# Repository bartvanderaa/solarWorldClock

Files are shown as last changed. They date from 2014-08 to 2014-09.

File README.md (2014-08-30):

solarWorldClock
===============

The Arduino based Solar World Clock<br>

Bart van der Aa<br>
info@bartvanderaa.com<br>
2013-2014<br>
 
General notes:<br>
The Solar World Clock (SWC) project has been in my mind for about 10 years now, and finally I found a suitable platform (the Arduino) to actually built it. 
But, first things first, what is the WSC project about? And secondly, how can we built one?<br>

The first question is actually fairly easy to answer. Imagine the map of the world where the sun's intensity is projected on the surface of this map. One could read the approximate time by tracing the location of the sun, just by identifying on which parts of the globe it is day- or nighttime. This, in brief, is the working principle of the WSC. Obviously, it is difficult to know the time in absolute terms, but who needs that anyway ;-) <br>
 
Notes on algorithm:<br>
The program uses a real-time-clock (RTC) to keep track of date and time. Based on date, time, and location the solar intensity is computed. A vector of intensity values (0-255) is then send to ShiftPWM to control an array of LEDs. Time can now be read based on the digitally projected solar intensity. <br>
 
Sunset-Sunrise part:<br>
Eastern longitude positive, Western longitude negative, Northern latitude positive and Southern latitude negative. <br>
 
PWM part:<br>
If flickering of the LEDs occurs try to adjust the PWM frequency.<br>
 
Credits go to:<br>
Solar intensity part by The Renewable Resource Data Center (RReDC), downloaded 2014;<br>
RTC part by Michael Margolis, downloaded 2014<br>
PWM part by Elco Jacobs, updated August 2012<br>

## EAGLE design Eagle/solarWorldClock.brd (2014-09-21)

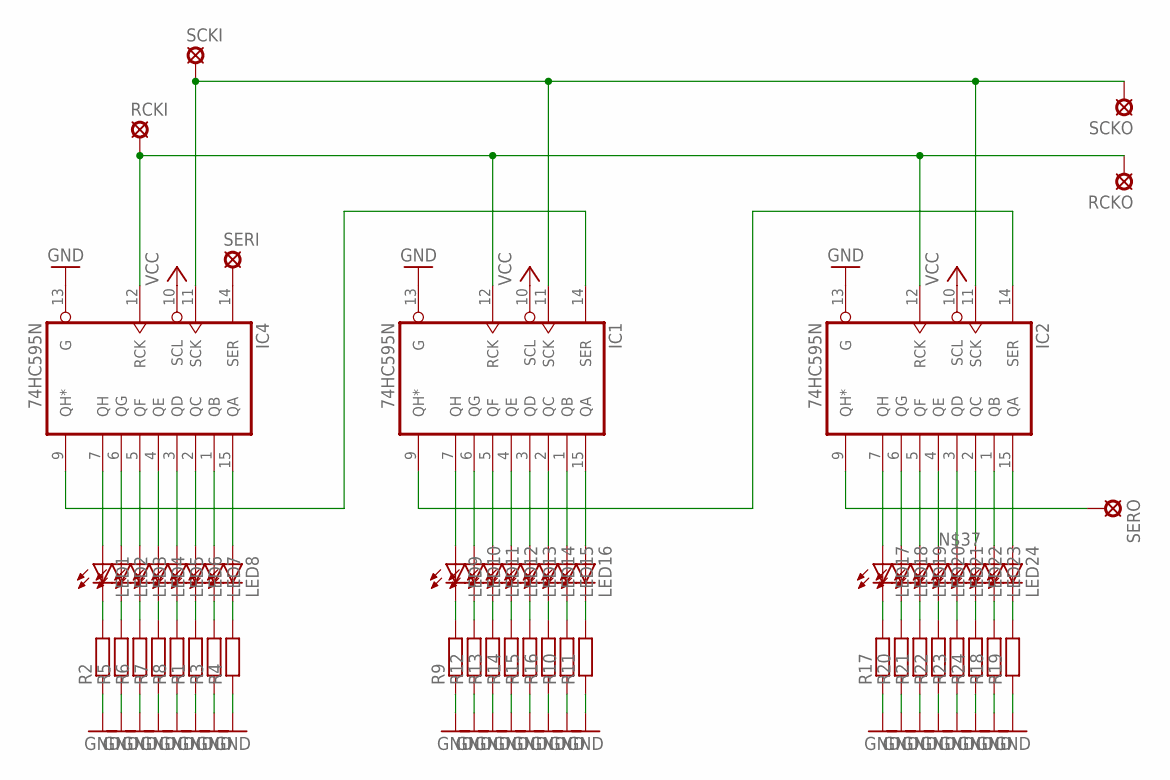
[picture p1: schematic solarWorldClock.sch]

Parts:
IC1, IC2, IC4: 74HC595N; DIL16
LED1, LED2, LED3, LED4, LED5, LED6, LED7, LED8, LED9, LED10, LED11, LED12, LED13, LED14, LED15, LED16, LED17, LED18, LED19, LED20, LED21, LED22, LED23, LED24: LEDLZR181; LZR181
R1, R2, R3, R4, R5, R6, R7, R8, R9, R10, R11, R12, R13, R14, R15, R16, R17, R18, R19, R20, R21, R22, R23, R24: R-EU_0207/7; 0207/7
RCKI: LSP10
RCKO: LSP10
SCKI: LSP10
SCKO: LSP10
SERI: LSP10
SERO: LSP10

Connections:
GND: IC1.8 (GND), IC1.13 (G), IC2.8 (GND), IC2.13 (G), IC4.8 (GND), IC4.13 (G), R1.1, R2.1, R3.1, R4.1, R5.1, R6.1, R7.1, R8.1, R9.1, R10.1, R11.1, R12.1, R13.1, R14.1, R15.1, R16.1, R17.1, R18.1, R19.1, R20.1, R21.1, R22.1, R23.1, R24.1
unnamed: IC4.7 (QH), LED1.A
unnamed: LED1.K (C), R2.2
unnamed: IC4.6 (QG), LED2.A
unnamed: IC4.5 (QF), LED3.A
unnamed: IC4.4 (QE), LED4.A
unnamed: IC4.3 (QD), LED5.A
unnamed: IC4.2 (QC), LED6.A
unnamed: IC4.1 (QB), LED7.A
unnamed: IC4.15 (QA), LED8.A
unnamed: LED2.K (C), R5.2
unnamed: LED3.K (C), R6.2
unnamed: LED4.K (C), R7.2
unnamed: LED5.K (C), R8.2
unnamed: LED6.K (C), R1.2
unnamed: LED7.K (C), R3.2
unnamed: LED8.K (C), R4.2
unnamed: IC1.7 (QH), LED9.A
unnamed: IC1.6 (QG), LED10.A
unnamed: IC1.5 (QF), LED11.A
unnamed: IC1.4 (QE), LED12.A
unnamed: IC1.3 (QD), LED13.A
unnamed: IC1.2 (QC), LED14.A
unnamed: IC1.1 (QB), LED15.A
unnamed: IC1.15 (QA), LED16.A
unnamed: LED9.K (C), R9.2
unnamed: LED10.K (C), R12.2
unnamed: LED11.K (C), R13.2
unnamed: LED12.K (C), R14.2
unnamed: LED13.K (C), R15.2
unnamed: LED14.K (C), R16.2
unnamed: LED15.K (C), R10.2
unnamed: LED16.K (C), R11.2
unnamed: IC2.9 (QH*), SERO.MP
unnamed: IC1.14 (SER), IC4.9 (QH*)
unnamed: IC2.7 (QH), LED17.A
unnamed: IC2.6 (QG), LED18.A
unnamed: IC2.5 (QF), LED19.A
unnamed: IC2.4 (QE), LED20.A
unnamed: IC2.3 (QD), LED21.A
unnamed: IC2.2 (QC), LED22.A
unnamed: IC2.1 (QB), LED23.A
unnamed: IC2.15 (QA), LED24.A
unnamed: LED17.K (C), R17.2
unnamed: LED18.K (C), R20.2
unnamed: LED19.K (C), R21.2
unnamed: LED20.K (C), R22.2
unnamed: LED21.K (C), R23.2
unnamed: LED22.K (C), R24.2
unnamed: LED23.K (C), R18.2
unnamed: LED24.K (C), R19.2
unnamed: IC1.9 (QH*), IC2.14 (SER)
unnamed: IC1.12 (RCK), IC2.12 (RCK), IC4.12 (RCK), RCKI.MP, RCKO.MP
unnamed: IC1.11 (SCK), IC2.11 (SCK), IC4.11 (SCK), SCKI.MP, SCKO.MP
unnamed: IC4.14 (SER), SERI.MP
VCC: IC1.10 (SCL), IC1.16 (VCC), IC2.10 (SCL), IC2.16 (VCC), IC4.10 (SCL), IC4.16 (VCC)

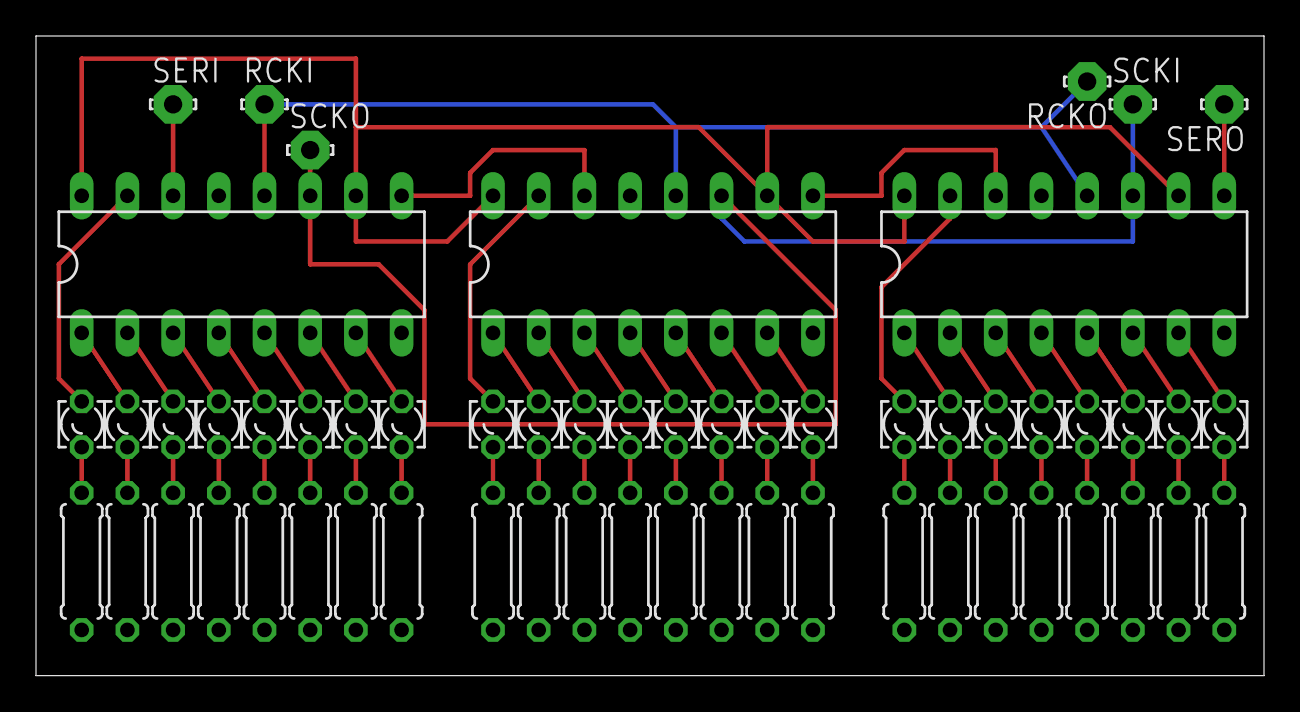
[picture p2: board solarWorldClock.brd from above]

Board: 2 copper layers, 68.2 x 35.5 mm, 57 parts (0 on the bottom side), 56 nets.

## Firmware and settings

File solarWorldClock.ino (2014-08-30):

/**********************************************************************
 SolarWorldClock
 Bart van der Aa
 info@bartvanderaa.com
 2013-2014
 
 General notes:
 The Solar World Clock (SWC) project has been in my mind for about 10 years now, and finally I found a suitable platform (the Arduino) to actually built it. 
 But, first things first, what is the WSC project about? And secondly, how can we built one?

 The first question is actually fairly easy to answer. Imagine the map of the world where the sun's intensity is projected on the surface of this map.   
 One could read the approximate time by tracing the location of the sun, just by identifying on which parts of the globe it is day- or nighttime. 
 This, in brief, is the working principle of the WSC. Obviously, it is difficult to know the time in absolute terms, but who needs that anyway ;-)
 
 Notes on alorithm:
 The program uses a real-time-clock (RTC) to keep track of date and time. Based on date, time, and location the solar intensity is computed.
 A vector of intensity values (0-255) is then send to ShiftPWM to control an array of LEDs. Time can now be read based on the digitally projected solar intensity. 
 
 Sunset-Sunrise part:
 Eastern longitude positive, Western longitude negative       
 Northern latitude positive, Southern latitude negative
 
 PWM part:
 If flickering of the LEDs occurs try to adjust the PWM frequency.
 
 Credits go to:
 Solar intensity part by The Renewable Resource Data Center (RReDC), downloaded 2014
 RTC part by Michael Margolis, downloaded 2014 
 PWM part by Elco Jacobs, updated August 2012
 
 ***********************************************************************/

// Initialize Shift PWM before loading libraries. Note that dataPin and clockPin are predefined on pin 11 and pin 13, respectively.
const int ShiftPWM_latchPin = 4;
const bool ShiftPWM_invertOutputs = false;
const bool ShiftPWM_balanceLoad = false;

// Include other libraries
#include <ShiftPWM.h>
#include <Wire.h>
#include "RTClib.h"  
#include <stdio.h>
#include <math.h>
#include <stdlib.h>
#include <string.h>
#include "solpos00.h" 

// Initialize RTC
RTC_DS1307 RTC;

// Initialize shift-registers
void inOutAll(void);
unsigned char maxBrightness = 255;
unsigned char pwmFrequency = 75;
unsigned int numRegisters = 3;
unsigned int numOutputs = numRegisters*8;

// Coordinate settings
double lat = 00.70;// 57.70; // lattitude, Göteborg
double lonVec[] = {
  -165, -150, -135, -120, -105, -90, -75, -60, -45, -30, -15, 0, 15, 30, 45, 60, 75, 90, 105, 120, 135, 150, 165, 180}; // Time-zone central longitude coordiantes 
double intensityVec[24];
//int normIntensity[24];
double maxIntensity = 1375; 

int *normIntensity = (int*)calloc(24,sizeof(int));

/*============================================================================*/
// Setup loop
/*============================================================================*/
void setup(){

  // Begin the Serial connection 
  Serial.begin(9600);

  // Instantiate the RTC
  Wire.begin();
  RTC.begin();

  // Check if the RTC is running.
  if (! RTC.isrunning()) {
    Serial.println("RTC is NOT running");
  }

  // This section grabs the current datetime and compares it to
  // the compilation time.  If necessary, the RTC is updated.
  DateTime now = RTC.now();
  DateTime compiled = DateTime(__DATE__, __TIME__);
  if (now.unixtime() < compiled.unixtime()) {
    Serial.println("RTC is older than compile time! Updating");
    RTC.adjust(DateTime(__DATE__, __TIME__));
  }
  
  // Sets the number of 8-bit registers that are used.
  ShiftPWM.SetAmountOfRegisters(numRegisters);
  
  // Set PWM frequency and Maximum brightness
  ShiftPWM.Start(pwmFrequency,maxBrightness);
  
  Serial.println("Setup complete.");
}

/*============================================================================*/
// main loop 
/*============================================================================*/
void loop(){    

  // Solar intensity alg initi
  struct posdata pd, *pdat;
  long retval;
  pdat = &pd;
  S_init(pdat);

  // Get actual time and reformat
  DateTime now = RTC.now();   
  pdat->function &= ~S_DOY;
  pdat->month = now.month();
  pdat->day   = now.day();
  pdat->year  = now.year(); 
  pdat->hour  = now.hour();
  pdat->minute = now.minute();
  pdat->second = now.second();
  pdat->timezone  = 1.0;

  // Solar intensity
  pdat->latitude  =  lat; 
  for (int ii=0; ii<24; ii++){  
    pdat->longitude = lonVec[ii];
    retval = S_solpos(pdat);
    intensityVec [ii] = pdat->etr;
    normIntensity[ii] = round((pdat->etr)/maxIntensity*255);
  }  

  if(Serial.available()){
    if(Serial.peek() == 'l'){
      // Print information about the interrupt frequency, duration and load on your program
      ShiftPWM.PrintInterruptLoad();
    }
    while (Serial.read() >= 0){
      ; // flush remaining characters
    }
  }
  
  // Switch all Pins on
  ShiftPWM.Set24Pins(normIntensity);

  
  // Display the current time
  Serial.print("Current time: ");
  Serial.print(now.year(), DEC);
  Serial.print('/');
  Serial.print(now.month(), DEC);
  Serial.print('/');
  Serial.print(now.day(), DEC);
  Serial.print(' ');
  Serial.print(now.hour(), DEC);
  Serial.print(':');
  Serial.print(now.minute(), DEC);
  Serial.print(':');
  Serial.print(now.second(), DEC);
  
  Serial.println();
  for (int ii=0; ii<24; ii++){
    Serial.print(normIntensity[ii]);
    Serial.println();
  } 
  
  Serial.println();
  delay(5000);
}

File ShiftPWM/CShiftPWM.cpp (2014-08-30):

/*
CShiftPWM.cpp - ShiftPWM.h - Library for Arduino to PWM many outputs using shift registers
Copyright (c) 2011-2012 Elco Jacobs, www.elcojacobs.com
All right reserved.

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
You should have received a copy of the GNU Lesser General Public
License along with this library; if not, write to the Free Software
Foundation, Inc., 51 Franklin St, Fifth Floor, Boston, MA  02110-1301  USA
*/

/* workaround for a bug in WString.h */
#define F(string_literal) (reinterpret_cast<const __FlashStringHelper *>(PSTR(string_literal)))

#include "CShiftPWM.h"
#include <Arduino.h>

CShiftPWM::CShiftPWM(int timerInUse, bool noSPI, int latchPin, int dataPin, int clockPin) :  // Constants are set in initializer list
					m_timer(timerInUse), m_noSPI(noSPI), m_latchPin(latchPin), m_dataPin(dataPin), m_clockPin(clockPin){
	m_ledFrequency = 0;
	m_maxBrightness = 0;
	m_amountOfRegisters = 0;
	m_amountOfOutputs = 0;
	m_counter = 0;
	m_pinGrouping = 1; // Default = RGBRGBRGB... PinGrouping = 3 means: RRRGGGBBBRRRGGGBBB...

	unsigned char * m_PWMValues=0;
}

CShiftPWM::~CShiftPWM() {
	if(m_PWMValues>0){
		free( m_PWMValues );
	}
}

bool CShiftPWM::IsValidPin(int pin){
	if(pin<m_amountOfOutputs){
		return 1;
	}
	else{
		Serial.print(F("Error: Trying to write duty cycle of pin "));
		Serial.print(pin);
		Serial.print(F(" , while number of outputs is "));
		Serial.print(m_amountOfOutputs);
		Serial.print(F(" , numbered 0-"));
		Serial.println(m_amountOfOutputs-1);
		delay(1000);
		return 0;
	}
}


void CShiftPWM::SetOne(int pin, unsigned char value){
	if(IsValidPin(pin) ){
		m_PWMValues[pin]=value;
	}
}

void CShiftPWM::SetAll(unsigned char value){
	for(int k=0 ; k<(m_amountOfOutputs);k++){
		m_PWMValues[k]=value;
	}
}

void CShiftPWM::Set24Pins(int value[24]){
	for(int k=0 ; k<(m_amountOfOutputs);k++){
		m_PWMValues[k]=value[k];
	}
}

void CShiftPWM::Set288Pins(int value[288]){
	for(int k=0 ; k<(m_amountOfOutputs);k++){
		m_PWMValues[k]=value[k];
	}
}

void CShiftPWM::SetGroupOf2(int group, unsigned char v0,unsigned char v1, int offset){
	int skip = m_pinGrouping*(group/m_pinGrouping); // is not equal to 2*group. Division is rounded down first.
	if(IsValidPin(group+skip+offset+m_pinGrouping) ){
		m_PWMValues[group+skip+offset]					=v0;
		m_PWMValues[group+skip+offset+m_pinGrouping]	=v1;
	}
}

void CShiftPWM::SetGroupOf3(int group, unsigned char v0,unsigned char v1,unsigned char v2, int offset){
	int skip = 2*m_pinGrouping*(group/m_pinGrouping); // is not equal to 2*group. Division is rounded down first.
	if(IsValidPin(group+skip+offset+2*m_pinGrouping) ){
		m_PWMValues[group+skip+offset]					=v0;
		m_PWMValues[group+skip+offset+m_pinGrouping]	=v1;
		m_PWMValues[group+skip+offset+m_pinGrouping*2]	=v2;
	}
}

void CShiftPWM::SetGroupOf4(int group, unsigned char v0,unsigned char v1,unsigned char v2,unsigned char v3, int offset){
	int skip = 3*m_pinGrouping*(group/m_pinGrouping); // is not equal to 2*group. Division is rounded down first.
	if(IsValidPin(group+skip+offset+3*m_pinGrouping) ){
		m_PWMValues[group+skip+offset]					=v0;
		m_PWMValues[group+skip+offset+m_pinGrouping]	=v1;
		m_PWMValues[group+skip+offset+m_pinGrouping*2]	=v2;
		m_PWMValues[group+skip+offset+m_pinGrouping*3]	=v3;
	}
}

void CShiftPWM::SetGroupOf5(int group, unsigned char v0,unsigned char v1,unsigned char v2,unsigned char v3,unsigned char v4, int offset){
	int skip = 4*m_pinGrouping*(group/m_pinGrouping); // is not equal to 2*group. Division is rounded down first.
	if(IsValidPin(group+skip+offset+4*m_pinGrouping) ){
		m_PWMValues[group+skip+offset]					=v0;
		m_PWMValues[group+skip+offset+m_pinGrouping]	=v1;
		m_PWMValues[group+skip+offset+m_pinGrouping*2]	=v2;
		m_PWMValues[group+skip+offset+m_pinGrouping*3]	=v3;
		m_PWMValues[group+skip+offset+m_pinGrouping*4]	=v4;
	}
}

void CShiftPWM::SetRGB(int led, unsigned char r,unsigned char g,unsigned char b, int offset){
	int skip = 2*m_pinGrouping*(led/m_pinGrouping); // is not equal to 2*led. Division is rounded down first.
	if(IsValidPin(led+skip+offset+2*m_pinGrouping) ){
		m_PWMValues[led+skip+offset]					=( (unsigned int) r * m_maxBrightness)>>8;
		m_PWMValues[led+skip+offset+m_pinGrouping]		=( (unsigned int) g * m_maxBrightness)>>8;
		m_PWMValues[led+skip+offset+2*m_pinGrouping]	=( (unsigned int) b * m_maxBrightness)>>8;
	}
}

void CShiftPWM::SetAllRGB(unsigned char r,unsigned char g,unsigned char b){
	for(int k=0 ; (k+3*m_pinGrouping-1) < m_amountOfOutputs; k+=3*m_pinGrouping){
		for(int l=0; l<m_pinGrouping;l++){
			m_PWMValues[k+l]				=	( (unsigned int) r * m_maxBrightness)>>8;
			m_PWMValues[k+l+m_pinGrouping]	=	( (unsigned int) g * m_maxBrightness)>>8;
			m_PWMValues[k+l+m_pinGrouping*2]	=	( (unsigned int) b * m_maxBrightness)>>8;
		}
	}
}

void CShiftPWM::SetHSV(int led, unsigned int hue, unsigned int sat, unsigned int val, int offset){
	unsigned char r,g,b;
	unsigned int H_accent = hue/60;
	unsigned int bottom = ((255 - sat) * val)>>8;
	unsigned int top = val;
	unsigned char rising  = ((top-bottom)  *(hue%60   )  )  /  60  +  bottom;
	unsigned char falling = ((top-bottom)  *(60-hue%60)  )  /  60  +  bottom;

	switch(H_accent) {
	case 0:
		r = top;
		g = rising;
		b = bottom;
		break;

	case 1:
		r = falling;
		g = top;
		b = bottom;
		break;

	case 2:
		r = bottom;
		g = top;
		b = rising;
		break;

	case 3:
		r = bottom;
		g = falling;
		b = top;
		break;

	case 4:
		r = rising;
		g = bottom;
		b = top;
		break;

	case 5:
		r = top;
		g = bottom;
		b = falling;
		break;
	}
	SetRGB(led,r,g,b,offset);
}

void CShiftPWM::SetAllHSV(unsigned int hue, unsigned int sat, unsigned int val){
	// Set the first LED
	SetHSV(0, hue, sat, val);
	// Copy RGB values all LED's.
	SetAllRGB(m_PWMValues[0],m_PWMValues[m_pinGrouping],m_PWMValues[2*m_pinGrouping]);
}

// OneByOne functions are usefull for testing all your outputs
void CShiftPWM::OneByOneSlow(void){
	OneByOne_core(1024/m_maxBrightness);
}

void CShiftPWM::OneByOneFast(void){
	OneByOne_core(1);
}

void CShiftPWM::OneByOne_core(int delaytime){
	int pin,brightness;
	SetAll(0);
	for(int pin=0;pin<m_amountOfOutputs;pin++){
		for(brightness=0;brightness<m_maxBrightness;brightness++){
			m_PWMValues[pin]=brightness;
			delay(delaytime);
		}
		for(brightness=m_maxBrightness;brightness>=0;brightness--){
			m_PWMValues[pin]=brightness;
			delay(delaytime);
		}
	}
}
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
